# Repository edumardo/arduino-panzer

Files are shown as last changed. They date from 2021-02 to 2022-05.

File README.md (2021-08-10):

# arduino-panzer

Because buying one was too easy, better build and program it yourself!

This project aims to control a RC tank using a programmable board, arduino, and implement the main features of other commercial products such as Heng Long, Toro or Taigen: classic movement, turret rotation, gun elevation, sound, smoke, lights etc.

## How it works?

You can see test videos of implemented features [here](https://www.youtube.com/playlist?list=PLfADmksLEUYKfFm-LOJsjtZ3TI8cin0g5).

(http://www.youtube.com/watch?v=NVqAsgg3tQk "driving test")

## Parts

Currently I have a heng long chassis with gearbox (2 DC motors), turret rotation gearbox, airsoft gun unit, sound unit and smoke generator. I control it with a bluetooth ps2 controller and several TB6612FNG drivers. See the wiring-diagram for more details.

Hardware:

* 1 x Arduino mega.
* 3 x TB6612FNG.
* 1 x Heng Long chassis with gearbox (2 DC motors).
* 1 x Turret rotation gearbox.
* 1 x MG90S servo for gun recoil.
* 1 x MG90S servo for gun elevation.
* 1 x Dasmikro TBS Mini sound unit.
* 1 x 8 Ohm speaker.
* 1 x PS2 controller (bluetooth is not necessary).
* 1 x battery (I'm using a 14.5V 2.15Ah from a robot vacuum cleaner).
* A lot of jumper wires.

## Dependencies

* [DifferentialSteering](https://github.com/edumardo/DifferentialSteering), available in the [library manager](https://www.arduino.cc/en/guide/libraries#).
* [TBSMini](https://github.com/edumardo/TBSMini).
* [PS2X_lib](https://github.com/madsci1016/Arduino-PS2X).
* [arduino-timer](https://github.com/contrem/arduino-timer), available in the [library manager](https://www.arduino.cc/en/guide/libraries#).
* [AsyncServo](https://github.com/luisllamasbinaburo/Arduino-AsyncServo).  available in the [library manager](https://www.arduino.cc/en/guide/libraries#).

## Features

| Feature | Status | Description |
|---|---|---|
| PS2 Pad control | ✔️ Done | |
| PS2 left analog stick control | ✔️ Done | |
| Turret rotation | ✔️ Done | |
| Gun elevation | ✔️ Done | |
| Airsoft gun shoot | ⚠️ Pending | |
| Smoke unit | ✔️ Done | |
| Sound unit | ⚙️ In progress | |
| Start / Stop sequence | ⚙️ In progress | |
| Hull MG firing sound | ⚙️ In progress | |
| Hull MG firing led | ⚠️ Pending | |

## Wiring diagram

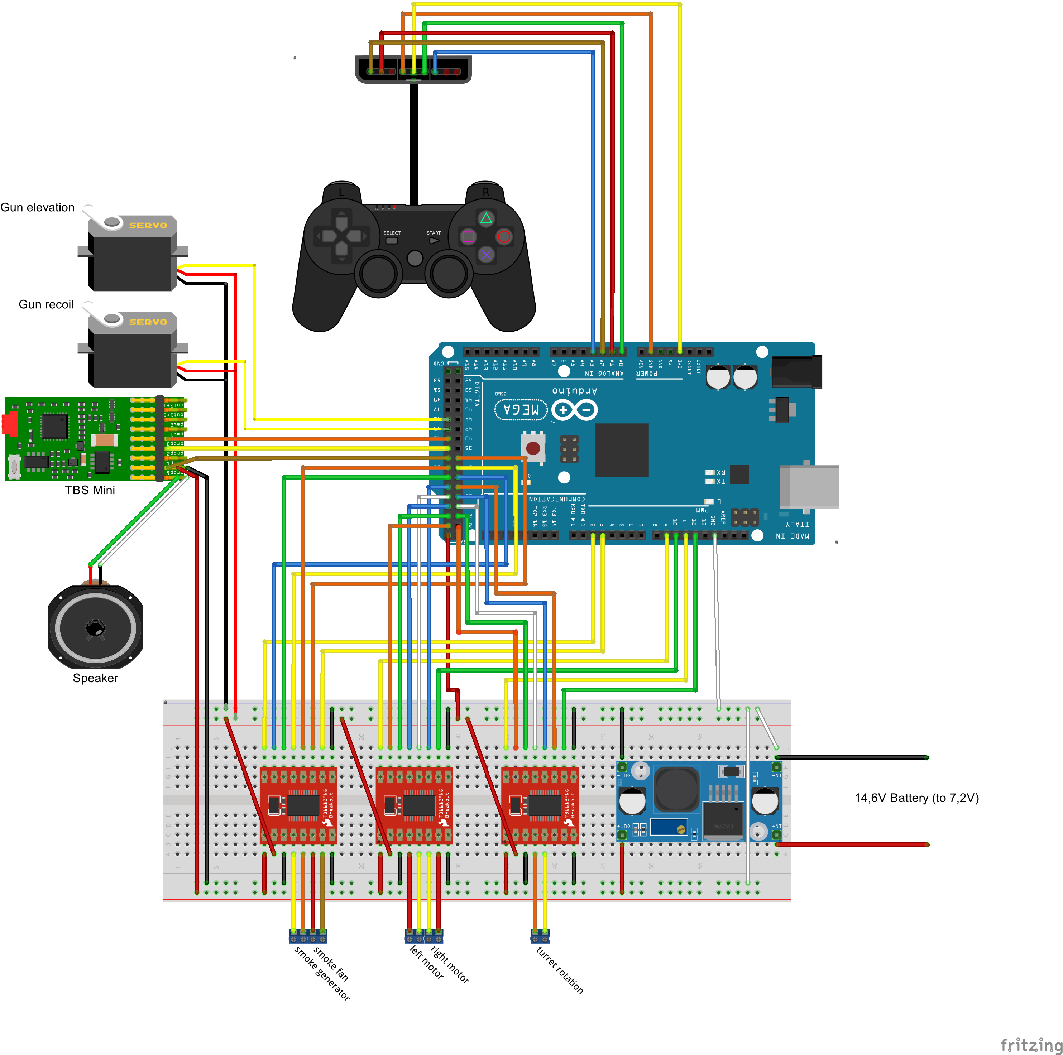
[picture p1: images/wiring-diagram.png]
Wiring diagram


## Arduino Mega Timers, PWMs and Servos

PWMs:

|Registrer | Pin | Timer  | Frequency | PWM Freq | Prescaler (* default) |
|--- |--- |---|---|---|---|
|TCCR0B | 4, 13 | Timer0 | 62500 Hz  | 980 Hz | 1, 8, 64*, 256, 1024 |
|TCCR1B | 11, 12 | Timer1 | 31250 Hz  | 490 Hz | 1, 8, 64*, 256, 1024 |
|TCCR2B | 9, 10 | Timer2 | 31250 Hz  | 490 Hz | 1, 8, 32, 64*, 128, 256, 1024 |
|TCCR3B | 2, 3, 5 | Timer3 | 31250 Hz  | 490 Hz | 1, 8, 64*, 256, 1024 |
|TCCR4B | 6, 7, 8 | Timer4 | 31250 Hz  | 490 Hz | 1, 8, 64*, 256, 1024 |
|TCCR5B | 44, 45, 46 | Timer5 | 31250 Hz  | 490 Hz | 1, 8, 64*, 256, 1024 |

[Servo](https://www.arduino.cc/reference/en/libraries/servo/) library:

| Nº Servos | Timer | Lost PWMs |
|---|--- |---|
| <= 12 | 5 | 44, 45, 46 |
| <= 24 | 1, 5 | 11, 12, 44, 45, 46 |
| <= 36 | 1, 3, 5 | 2, 3, 5, 11, 12, 44, 45, 46 |
| <= 48 | 1, 3, 4, 5 | All |

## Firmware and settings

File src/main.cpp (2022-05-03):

#include <Arduino.h>

#include <ArduinoPanzer.h>
#include "AsyncServoLib.h"
//--------------------------------------------------------------------------------------------------------------------------------------------------
ArduinoPanzer tank;

long debounceFireGunTime = 0;
long debounceStartStopTime = 0;
long debounceVolumeTime = 0;
//--------------------------------------------------------------------------------------------------------------------------------------------------
void setup() {

    Serial.begin(115200);
    Serial.println("Inicializamos Serial");

    delay(300);  //added delay to give wireless ps2 module some time to startup, before configuring it

    tank.begin();
}

//--------------------------------------------------------------------------------------------------------------------------------------------------
void loop() {

    if (tank.foundRadio() == false)
        return;

    tank.update();
    tank.readRadio();

    /* Turret rotation */
    if (tank.radioTurretRotation() != PS2_CENTER_STICK_VALUE) {
        tank.turretRotation().move(tank.radioTurretRotation());
        tank.soundUnit()->playSound(TBSMINI_SOUND_TURRET_ROTATION);
    }
    else {
        tank.turretRotation().disableMotor();
    }

    /* Gun elevation */
    if (tank.radioGunElevation() != PS2_CENTER_STICK_VALUE) {
        tank.gunElevation()->move(tank.radioGunElevation());
    }

    /* Analog stick driving */
    if(tank.radioSteeringThrottle() != PS2_CENTER_STICK_VALUE || tank.radioSteeringTurn() != PS2_CENTER_STICK_VALUE) {
        tank.driveDirection().move(tank.radioSteeringThrottle(), tank.radioSteeringTurn());
        int maxRadioSpeed = tank.maxRadioSpeed();
        tank.soundUnit()->setEngineSpeed(maxRadioSpeed);
        tank.smoker()->smoke(maxRadioSpeed);
    }
    /* Pad driving */
    else if (tank.radioButton(CONTROLLER_BUTTON_DRIVE_THROTTLE) || tank.radioButton(CONTROLLER_BUTTON_DRIVE_RIGHT) || tank.radioButton(CONTROLLER_BUTTON_DRIVE_LEFT) || tank.radioButton(CONTROLLER_BUTTON_DRIVE_REVERSE) ) {
        tank.driveDirection().move(tank.radioDriveThrottle(), tank.radioDriveReverse(), tank.radioDriveLeft(), tank.radioDriveRight());
        tank.soundUnit()->setEngineSpeed(90);        // [0, 127]
        tank.smoker()->smoke(CONTROLLER_BUTTON_DRIVE_THROTTLE);
    }
    else {
        tank.driveDirection().disableMotors();
        tank.soundUnit()->idleEngine();
        tank.smoker()->idle();
    }

    /* Fire gun */
    if ((tank.radioButton(CONTROLLER_FIRE_GUN)) && (millis() - debounceFireGunTime > CONTROLLER_MS_DEBOUNCE) && (tank.gunRecoil()->readyToFire())) {
        debounceFireGunTime = millis();
        tank.gunRecoil()->fire();
        tank.soundUnit()->playSound(1);
    }

    /* Start/stop: engine and smoker */
    if ((tank.radioButton(CONTROLLER_STARTSTOP)) && (millis() - debounceStartStopTime > CONTROLLER_MS_DEBOUNCE)) {
        debounceStartStopTime = millis();
        tank.soundUnit()->toggleEngine();
        tank.smoker()->toggle();
    }

    /* Volume up/down */
    if ((tank.radioButton(CONTROLLER_VOLUMEUP)) && (millis() - debounceVolumeTime > CONTROLLER_MS_DEBOUNCE)) {
        debounceVolumeTime = millis();
        tank.soundUnit()->volumeUp();
    } else if ((tank.radioButton(CONTROLLER_VOLUMEDOWN)) && (millis() - debounceVolumeTime > CONTROLLER_MS_DEBOUNCE)) {
        debounceVolumeTime = millis();
        tank.soundUnit()->volumeDown();
    }

}

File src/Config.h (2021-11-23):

#ifndef CONFIG_H
#define CONFIG_H

#include <PS2X_lib.h>
#include "SmokeController.h"
//--------------------------------------------------------------------------------------------------------------------------------------------------
// Arduino Panzer main properties
//--------------------------------------------------------------------------------------------------------------------------------------------------
const uint16_t AP_GUN_RELOAD_TIME = 2000;

//--------------------------------------------------------------------------------------------------------------------------------------------------
// PS2 Radio
//--------------------------------------------------------------------------------------------------------------------------------------------------

// Miliseconds between reads
const uint8_t PS2_MS_BETWEEN_READS = 50;

// Milisecond to debounce buttons
const uint16_t PS2_MS_DEBOUNCE = 500;

// Stick properties
const int16_t PS2_MIN_STICK_VALUE    =   0;
const int16_t PS2_CENTER_STICK_VALUE = 128;
const int16_t PS2_MAX_STICK_VALUE    = 255;

// PS2 pins
const uint8_t PS2_DAT =   A2;
const uint8_t PS2_CMD =   A1;
const uint8_t PS2_SEL =   A0;
const uint8_t PS2_CLK =   A3;
const bool PS2_PRESSURES  = true;
const bool PS2_RUMBLE     = true;

//--------------------------------------------------------------------------------------------------------------------------------------------------
// nRF24 Radio
//--------------------------------------------------------------------------------------------------------------------------------------------------

// Miliseconds between reads
const uint8_t NRF24_MS_BETWEEN_READS = 50;

// Max miliseconds between reads to detect lost connection
const uint16_t NRF24_MS_MAX_TIME_BETWEEN_READS = 1000;

// Stick properties
const int16_t NRF24_MIN_STICK_VALUE    =    0;
const int16_t NRF24_CENTER_STICK_VALUE =  512;
const int16_t NRF24_MAX_STICK_VALUE    = 1023;

// NRF24 module pins
const uint8_t NRF24_CE  = 49;
const uint8_t NRF24_CSN = 53;

//--------------------------------------------------------------------------------------------------------------------------------------------------
// Radio controller
//--------------------------------------------------------------------------------------------------------------------------------------------------

// Radio button abstraction
#define CONTROLLER_TURRET_ROTATION       PSS_RX
#define CONTROLLER_GUN_ELEVATION         PSS_RY
#define CONTROLLER_STEERING_THROTTLE     PSS_LX
#define CONTROLLER_STEERING_TURN         PSS_LY
#define CONTROLLER_DRIVE_THROTTLE        PSAB_PAD_UP
#define CONTROLLER_BUTTON_DRIVE_THROTTLE PSB_PAD_UP
#define CONTROLLER_DRIVE_REVERSE         PSAB_PAD_DOWN
#define CONTROLLER_BUTTON_DRIVE_REVERSE  PSB_PAD_DOWN
#define CONTROLLER_DRIVE_LEFT            PSAB_PAD_LEFT
#define CONTROLLER_BUTTON_DRIVE_LEFT     PSB_PAD_LEFT
#define CONTROLLER_DRIVE_RIGHT           PSAB_PAD_RIGHT
#define CONTROLLER_BUTTON_DRIVE_RIGHT    PSB_PAD_RIGHT
#define CONTROLLER_FIRE_GUN              PSB_PINK
#define CONTROLLER_STARTSTOP             PSB_START
#define CONTROLLER_VOLUMEUP              PSB_L2
#define CONTROLLER_VOLUMEDOWN            PSB_R2

// Miliseconds to debounce buttons
const uint16_t CONTROLLER_MS_DEBOUNCE = PS2_MS_DEBOUNCE;

// Selected radio type
#define RADIO_PS2_TYPE      1
#define RADIO_NRF24_TYPE    2

#define SELECTED_RADIO_TYPE RADIO_PS2_TYPE

//--------------------------------------------------------------------------------------------------------------------------------------------------
// Drive direction
//--------------------------------------------------------------------------------------------------------------------------------------------------

// TB6612FNG Drive pins
const uint8_t  TB_DRIVE_APWM_PRESCALER =  1;
const uint8_t  TB_DRIVE_APWM           =  9;
const uint8_t  TB_DRIVE_AIN2           = 23;
const uint8_t  TB_DRIVE_AIN1           = 25;
const uint8_t  TB_DRIVE_STBY           = 27;
const uint8_t  TB_DRIVE_BIN1           = 29;
const uint8_t  TB_DRIVE_BIN2           = 31;
const uint8_t  TB_DRIVE_BPWM           = 10;
const uint16_t TB_DRIVE_BPWM_PRESCALER =  1;

// Max voltage percent sent to drive
const uint8_t DRIVE_MAX_VOLTAGE_PERCENT_ANALOG = 100;
const uint8_t DRIVE_MAX_VOLTAGE_PERCENT_PAD    =  80;

//--------------------------------------------------------------------------------------------------------------------------------------------------
// Turret rotation and gun elevation
//--------------------------------------------------------------------------------------------------------------------------------------------------

// TB6612FNG Turret rotation and gun elevation pins
const uint16_t TB_TURRETROTATION_PWM_PRESCALER =  1;
const uint8_t  TB_TURRETROTATION_PWM           = 11;
const uint8_t  TB_TURRETROTATION_IN2           = 22;
const uint8_t  TB_TURRETROTATION_IN1           = 24;
const uint8_t  TB_TURRETROTATION_STBY          = 26;
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

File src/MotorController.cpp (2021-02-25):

#include "MotorController.h"

/**
 * Constructor class.
 */
MotorController::MotorController() {

}

/**
 * Initialize pins, interval values of the controller, and the direcction of Y axis.
 * Pins are defined in pinout.h
 *
 * @param debugMode: true to enable serial.print, false otherwise.
 * @param stickMinValue: lowest value of the controller.
 * @param stickMaxValue: highest value of the controller.
 * @param invertYAxis: true if you want to invert Y axis, i.e., if you push forward the stick Y value decreases.
 */
void MotorController::begin(bool debugMode, int stickMinValue, int stickMaxValue, bool invertYAxis) {

    m_debugMode = debugMode;
    m_stickMinValue = stickMinValue;
    m_stickMaxValue = stickMaxValue;
    m_invertYAxis = invertYAxis;
    m_diffSteer.begin(PIVOT_Y_LIMIT);

    pinMode(TB_PWMA, OUTPUT);
    pinMode(TB_AIN2, OUTPUT);
    pinMode(TB_AIN1, OUTPUT);
    pinMode(TB_BIN1, OUTPUT);
    pinMode(TB_BIN2, OUTPUT);
    pinMode(TB_PWMB, OUTPUT);
    standby(true);
}

/**
 * Use differential steering to move the tank with [x,y] values, i.e., an analog stick.
 * Moving is from idle position [stickMinValue / 2, stickMaxValue / 2]. Yoy have to call this method when you detect
 * movement in your stick.
 *
 * ps2 controller example:
 *      controller interval : [0,255]
 *      idle position       : [128,128]
 *      analogMove(128,   0): Y axis decreases when push forward.
 *      analogMove(128, 255): Y axis increases when push back.
 *      analogMove(255, 128): stick to right.
 *      analogMove(  0, 128): stick to left.
 *
 *
 * @param x: value of x axis, interval set on begin().
 * @param y: value of y axis, interval set on begin().
 */
void MotorController::analogMove(int x, int y) {

    int diffSteerComputeRange = m_diffSteer.getComputeRange();

    // From PS2 range to DifferentialSteering Range.
    m_diffSteer.computeMotors(
        map(x,
            m_stickMinValue,
            m_stickMaxValue,
            -diffSteerComputeRange,
            diffSteerComputeRange)
        ,
        map(y,
            m_stickMinValue,
            m_stickMaxValue,
            m_invertYAxis ? diffSteerComputeRange : -diffSteerComputeRange,
            m_invertYAxis ? -diffSteerComputeRange : diffSteerComputeRange)
        );

    move(m_diffSteer.computedLeftMotor(), m_diffSteer.computedRightMotor());

    if (m_debugMode) {
        printXY(x, y);
    }
}

/**
 * Move tank with d-pad. Function expects [stickMinValue, stickMaxValue] values, when 0 means button is not pressed.
 *
 * @param padUp: up button value.
 * @param padDown: down button value.
 * @param padLeft: left button value.
 * @param padRight: right button value.
 */
void MotorController::padMove(int padUp, int padDown, int padLeft, int padRight) {

    if (padUp)          move(PAD_FIXED_SPEED, PAD_FIXED_SPEED);
    else if (padDown)   move(-PAD_FIXED_SPEED, -PAD_FIXED_SPEED);
    else if (padLeft)   move(0,  PAD_FIXED_SPEED);
    else if (padRight)  move(PAD_FIXED_SPEED, 0);

    if (m_debugMode) {
        printXY(padUp, padDown);
        printXY(padLeft, padRight);
    }
}

/**
 * Private method to send PWM values to the motors. Also it controls the direction of both motors.
 *
 * @param leftMotor: left motor value, [-127,127].
 * @param rightMotor: right motor value, [-127,127].
 */
void MotorController::move(int leftMotor, int rightMotor) {

    int diffSteerComputeRange = m_diffSteer.getComputeRange();

    standby(false);
    digitalWrite(TB_AIN1, (leftMotor  < 0) ? LOW  : HIGH);
    digitalWrite(TB_AIN2, (leftMotor  < 0) ? HIGH : LOW);
    digitalWrite(TB_BIN1, (rightMotor < 0) ? HIGH : LOW);
    digitalWrite(TB_BIN2, (rightMotor < 0) ? LOW  : HIGH);
    int pwml = abs(map(leftMotor,  -diffSteerComputeRange, diffSteerComputeRange, -255, 255));  // [0,255]
    int pwmr = abs(map(rightMotor, -diffSteerComputeRange, diffSteerComputeRange, -255, 255));  // [0,255]
    analogWrite(TB_PWMA, pwml);
    analogWrite(TB_PWMB, pwmr);

    if (m_debugMode) {
        printXY(leftMotor, rightMotor);
        if (leftMotor  < 0) Serial.print("[leftMotor reverse]"); else if (leftMotor == 0) Serial.print("[leftMotor idle]"); else Serial.print("[leftMotor forward]");
        if (rightMotor < 0) Serial.print("[rightMotor reverse]"); else if (rightMotor == 0) Serial.print("[rightMotor idle]"); else Serial.print("[rightMotor forward]");
        printXY(pwml, pwmr);
    }
}

/**
 * Enable or disable motors.
 *
 * @param standby: true to disable motors, false to enable.
 */
void MotorController::standby(bool standby) {

    digitalWrite(TB_STBY, standby ? LOW: HIGH);

    if (m_debugMode) {
        Serial.print("[MotorController] standbyMotors: "); Serial.println(standby ? "true" : "false");
    }
}

/**
 * Prints [x,y] to serial without new line.
 *
 * @param x: x value to print.
 * @param y: y value to print.
 */
void MotorController::printXY(int x, int y) {
    Serial.print("[");
    Serial.print(x, DEC);
    Serial.print(",");
    Serial.print(y, DEC);
    Serial.print("]");
}

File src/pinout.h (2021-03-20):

#ifndef PINOUT_H
#define PINOUT_H

/* PS2 pins */
#define PS2_PIN_DAT A2
#define PS2_PIN_CMD A1
#define PS2_PIN_SEL A0
#define PS2_PIN_CLK A3
const bool PS2_PRESSURES = true;
const bool PS2_RUMBLE    = true;

/* TB6612FNG Drive pins */
const int TB_DRIVE_PWMA =  4;
const int TB_DRIVE_AIN2 = 23;
const int TB_DRIVE_AIN1 = 25;
const int TB_DRIVE_STBY = 27;
const int TB_DRIVE_BIN1 = 29;
const int TB_DRIVE_BIN2 = 31;
const int TB_DRIVE_PWMB = 13;

/* TB6612FNG Turret rotation and gun elevation pins */
const int TB_TURRETROTATION_PWMA = 11;
const int TB_TURRETROTATION_AIN2 = 22;
const int TB_TURRETROTATION_AIN1 = 24;
const int TB_TURRETGUN_STBY      = 26;
const int TB_GUNELEVATION_BIN1   = 28;
const int TB_GUNELEVATION_BIN2   = 30;
const int TB_GUNELEVATION_PWMB   = 12;

#endif

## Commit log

2020-03-14 Stop motors when idle in analog move
2020-03-17 Wiring diagram
    [wiring-diagram.fzz]
2020-03-24 Hull MG firing led
2020-03-26 Feature/mg led firing (#1)
    * Initial implementation
    * Initial implementation in loop
    [wiring-diagram.fzz]
2020-03-26 led hull MG wiring diagram
2020-04-03 MotorController class
2020-04-05 fix precision in printXY
    [MotorController.cpp]
2020-04-06 controller interval and invert Y axis
    [MotorController.cpp, arduino-panzer.ino]
2021-02-28 Change pinout to free pwms
    [wiring-diagram.fzz]
2021-03-01 Rename MotorController class to DriveDirection
2021-03-02 Remove Hull MG firing led implementation
2021-03-02 Update pin names
2021-03-02 New class for DC motor controller with TB6612FNG
2021-03-02 Wiring diagram and features in progress
    [wiring-diagram.fzz]
2021-03-06 DCMotorController class for TB6612FNG and dc motor
2021-03-09 disable direction and PWM when no movement
2021-03-13 Set Voltage to motors by defauult
2021-03-20 pinout arduino mega
2021-03-23 wiring diagram and readme
    [wiring-diagram.fzz]
2021-03-23 fix PWMs table
2021-03-24 update servo info
2021-03-24 ps2 button abstration and consts
2021-03-29 only use props when is started. toggleEngine instead start/stop
2021-03-30 clean prints
2021-04-08 arduino-panzer main class
2021-04-13 refactor ArduinoPanzer.begin
2021-04-18 ps2 gamepad
    [wiring-diagram.fzz]
2021-04-26 wiring diagram and doc
    [wiring-diagram.fzz]
2021-04-28 Gun elevation refactor
    [wiring-diagram.fzz]
2021-04-29 fix wiring diagram
    [wiring-diagram.fzz]
2021-11-22 resetData in case of loss signal
